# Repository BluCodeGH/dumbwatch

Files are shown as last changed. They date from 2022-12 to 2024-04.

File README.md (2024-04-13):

# DumbWatch - An offline-first E-paper smartwatch

## Images

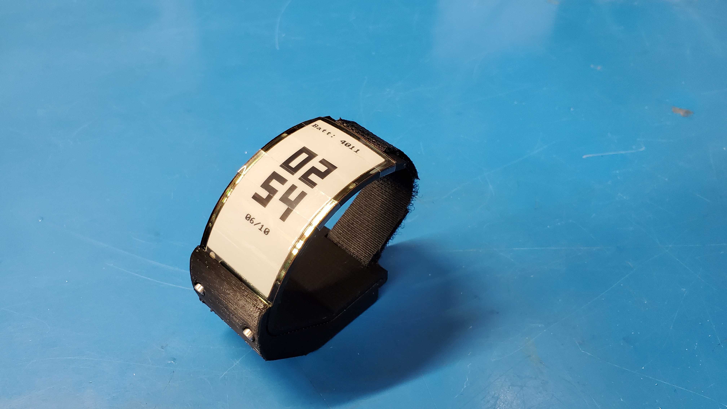
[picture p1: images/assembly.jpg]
Assembly

The final assembled watch.

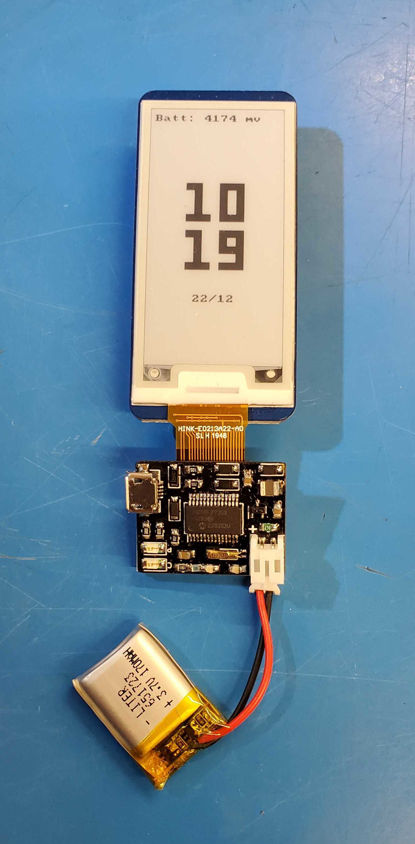
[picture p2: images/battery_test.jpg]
Battery Test

Running a battery life and RTC test using a stand-in display.

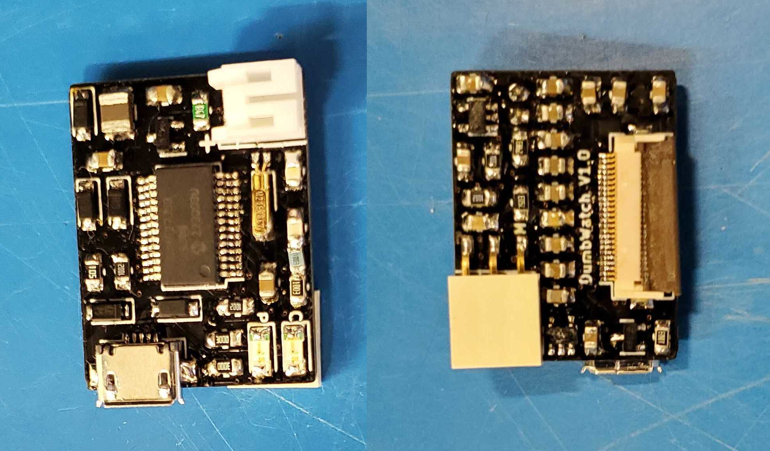
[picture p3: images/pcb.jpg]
PCB

Both sides of the custom PCB.

## Features

Dumbwatch is designed to be minimalist, with its most notable (anti-)feature being a lack of wireless connectivity. It still packs in a few nice-to-haves though:

- Two months of battery life on a 170 mAh LiPo
- LiPo charging over USB
- An E-paper dispay driver compatible with most common displays
- Communication over USB, e.g. for setting the time or loading your calendar for the day

The board is powered by the PIC18F27J53, which has an internal RTC connected to a 32.768 kHz watch crystal. I have not observed any noticble drift in the time thus far.

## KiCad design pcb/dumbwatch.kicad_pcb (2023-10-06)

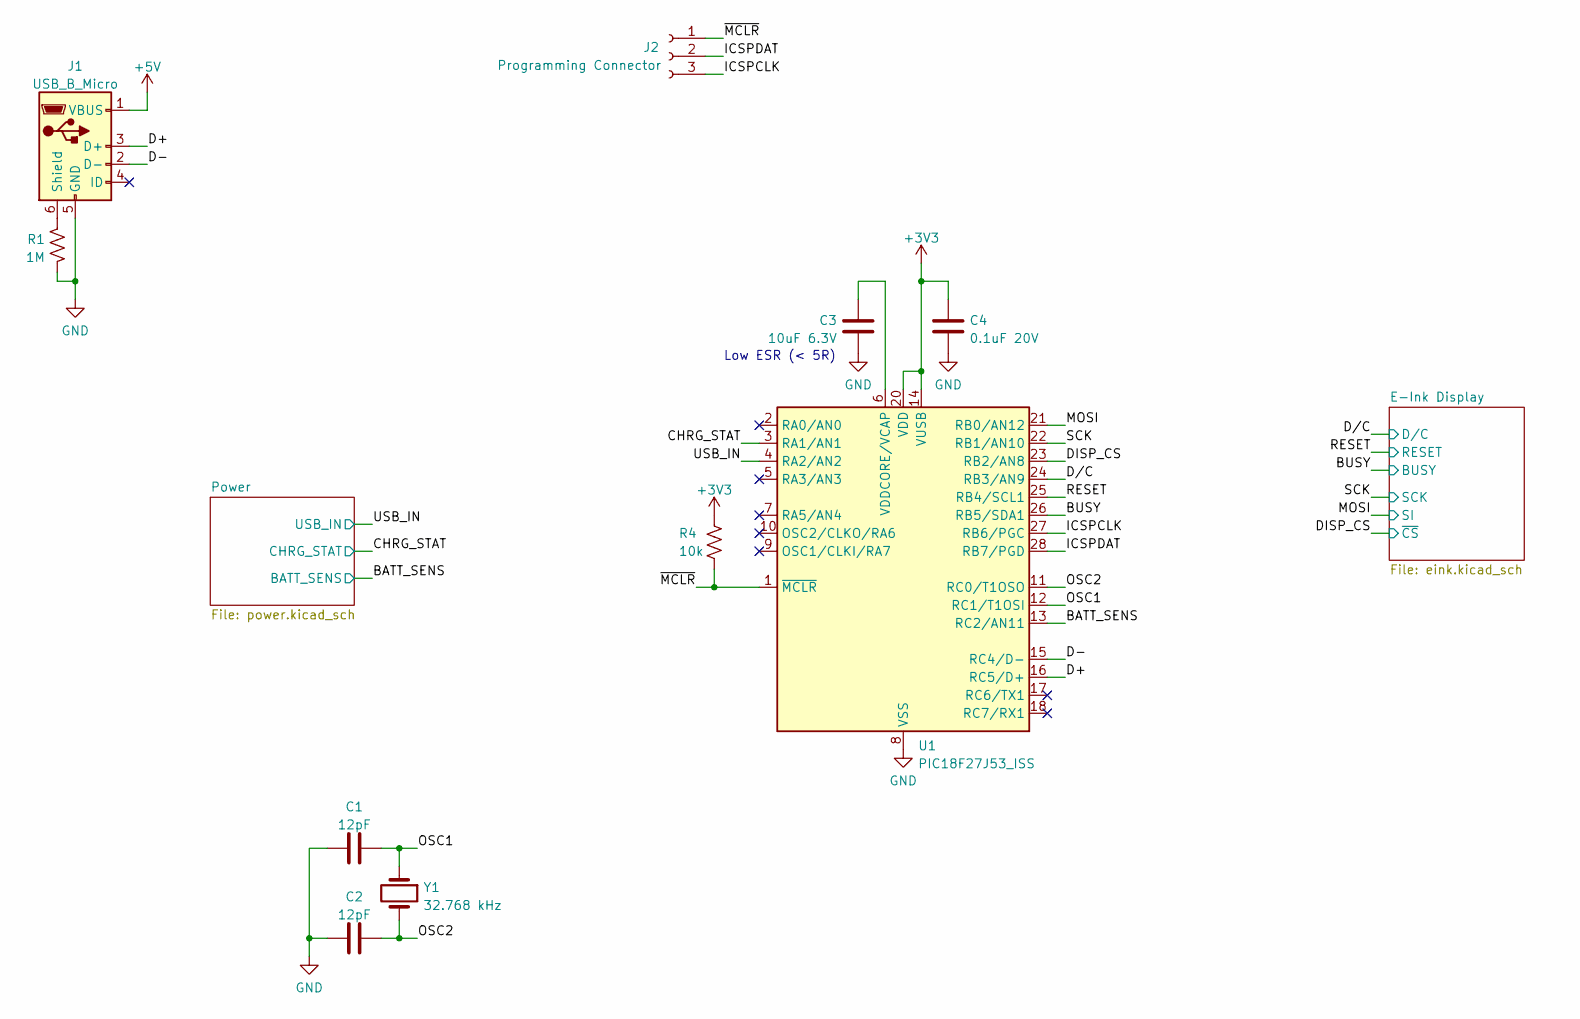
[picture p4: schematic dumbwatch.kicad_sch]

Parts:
C1, C2: 12pF; C_0805_2012Metric_Pad1.18x1.45mm_HandSolder
C3: 10uF 6.3V; C_0805_2012Metric_Pad1.18x1.45mm_HandSolder
C4: 0.1uF 20V; C_0805_2012Metric_Pad1.18x1.45mm_HandSolder
J1: USB_B_Micro; USB_Micro-B_Amphenol_10104110_Horizontal
J2: Programming Connector; PinHeader_3x2.54_SMD_90deg
R1: 1M; R_0805_2012Metric_Pad1.20x1.40mm_HandSolder
R4: 10k; R_0805_2012Metric_Pad1.20x1.40mm_HandSolder
U1: PIC18F27J53_ISS; SSOP-28_5.3x10.2mm_P0.65mm
Y1: 32.768 kHz; Crystal_SMD_MicroCrystal_MS3V-T1R

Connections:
+3V3: C4.2, R4.1, U1.14 (VUSB), U1.20 (VDD); also elsewhere on the board
+5V: J1.1 (VBUS); also elsewhere on the board
/BATT_SENS: U1.13 (RC2/AN11); also elsewhere on the board
/BUSY: U1.26 (RB5/SDA1); also elsewhere on the board
/CHRG_STAT: U1.3 (RA1/AN1); also elsewhere on the board
/D+: J1.3 (D+), U1.16 (RC5/D+)
/D-: J1.2 (D-), U1.15 (RC4/D-)
/DISP_CS: U1.23 (RB2/AN8); also elsewhere on the board
/D/C: U1.24 (RB3/AN9); also elsewhere on the board
/ICSPCLK: J2.3, U1.27 (RB6/PGC)
/ICSPDAT: J2.2, U1.28 (RB7/PGD)
/MOSI: U1.21 (RB0/AN12); also elsewhere on the board
/OSC1: C1.2, U1.12 (RC1/T1OSI), Y1.1
/OSC2: C2.2, U1.11 (RC0/T1OSO), Y1.2
/RESET: U1.25 (RB4/SCL1); also elsewhere on the board
/SCK: U1.22 (RB1/AN10); also elsewhere on the board
/USB_IN: U1.4 (RA2/AN2); also elsewhere on the board
/~MCLR: J2.1, R4.2, U1.1 (~MCLR)
GND: C1.1, C2.1, C3.1, C4.1, J1.5 (GND), R1.1, U1.8 (VSS), U1.19 (VSS); also elsewhere on the board
unnamed: C3.2, U1.6 (VDDCORE/VCAP)
unnamed: J1.6 (Shield), R1.2

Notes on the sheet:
Low ESR (< 5R)

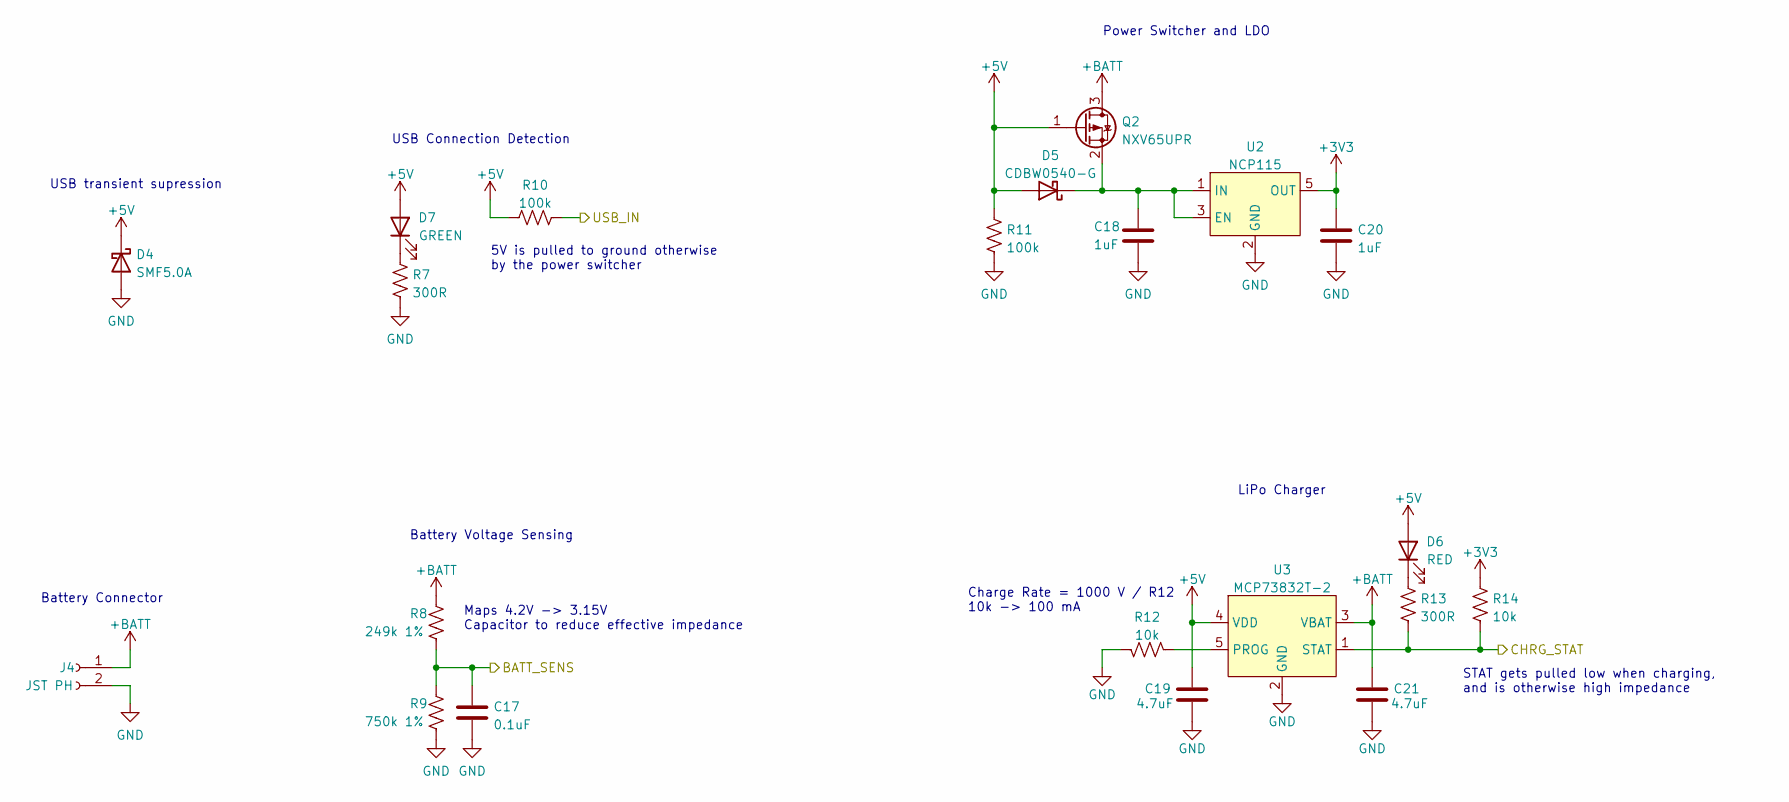
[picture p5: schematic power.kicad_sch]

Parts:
C17: 0.1uF; C_0805_2012Metric_Pad1.18x1.45mm_HandSolder
C18, C20: 1uF; C_0805_2012Metric_Pad1.18x1.45mm_HandSolder
C19, C21: 4.7uF; C_0805_2012Metric_Pad1.18x1.45mm_HandSolder
D4: SMF5.0A; D_SOD-123F
D5: CDBW0540-G; D_SOD-123
D6: RED; LED_1206_3216Metric_Pad1.42x1.75mm_HandSolder
D7: GREEN; LED_1206_3216Metric_Pad1.42x1.75mm_HandSolder
J4: JST PH; JST_PH_S2B-PH-K_1x02_P2.00mm_Horizontal
Q2: NXV65UPR; SOT-23
R7, R13: 300R; R_0805_2012Metric_Pad1.20x1.40mm_HandSolder
R8: 249k 1%; R_0805_2012Metric_Pad1.20x1.40mm_HandSolder
R9: 750k 1%; R_0805_2012Metric_Pad1.20x1.40mm_HandSolder
R10, R11: 100k; R_0805_2012Metric_Pad1.20x1.40mm_HandSolder
R12, R14: 10k; R_0805_2012Metric_Pad1.20x1.40mm_HandSolder
U2: NCP115; TSOT-23-5
U3: MCP73832T-2; SOT-23-5

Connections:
+3V3: C20.1, R14.1, U2.5 (OUT); also elsewhere on the board
+5V: C19.1, D4.1 (K), D5.2 (A), D6.2 (A), D7.2 (A), Q2.1 (G), R10.1, R11.1, U3.4 (VDD); also elsewhere on the board
+BATT: C21.1, J4.1, Q2.3 (D), R8.1, U3.3 (VBAT)
/BATT_SENS: C17.1, R8.2, R9.1; also elsewhere on the board
/CHRG_STAT: R13.2, R14.2, U3.1 (STAT); also elsewhere on the board
/USB_IN: R10.2; also elsewhere on the board
GND: C17.2, C18.2, C19.2, C20.2, C21.2, D4.2 (A), J4.2, R7.1, R9.2, R11.2, R12.2, U2.2 (GND), U3.2 (GND); also elsewhere on the board
unnamed: C18.1, D5.1 (K), Q2.2 (S), U2.1 (IN), U2.3 (EN)
unnamed: D6.1 (K), R13.1
unnamed: D7.1 (K), R7.2
unnamed: R12.1, U3.5 (PROG)

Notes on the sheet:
5V is pulled to ground otherwise by the power switcher
Battery Voltage Sensing
Charge Rate = 1000 V / R12 10k -> 100 mA
Maps 4.2V -> 3.15V Capacitor to reduce effective impedance
Battery Connector
USB Connection Detection
STAT gets pulled low when charging, and is otherwise high impedance
Power Switcher and LDO
USB transient supression
LiPo Charger

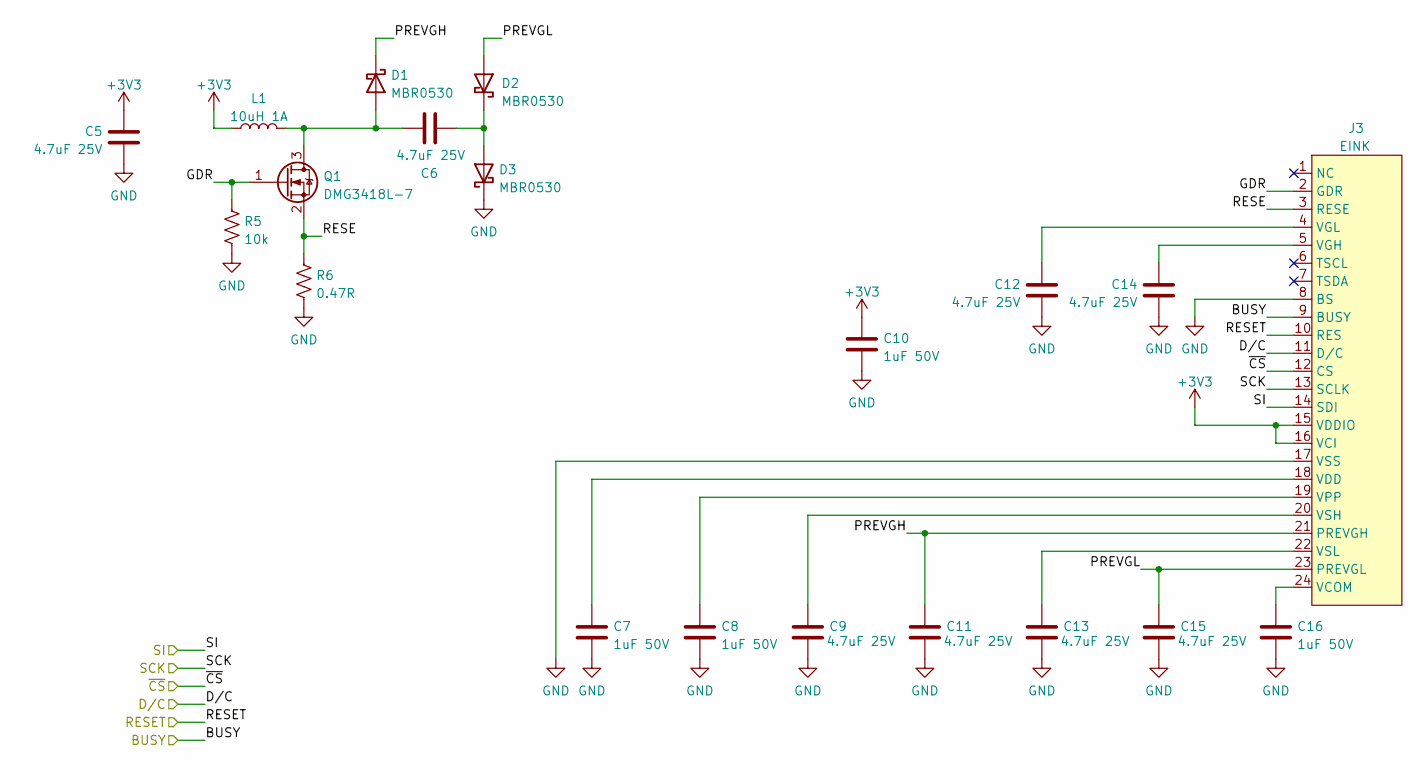
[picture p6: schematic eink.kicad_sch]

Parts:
C5, C6, C9, C11, C12, C13, C14, C15: 4.7uF 25V; C_0805_2012Metric_Pad1.18x1.45mm_HandSolder
C7, C8, C10, C16: 1uF 50V; C_0805_2012Metric_Pad1.18x1.45mm_HandSolder
D1, D2, D3: MBR0530; D_SOD-123
J3: EINK; Hirose_FH12-24S-0.5SH_1x24-1MP_P0.50mm_Horizontal
L1: 10uH 1A; L_1210_3225Metric_Pad1.42x2.65mm_HandSolder
Q1: DMG3418L-7; SOT-23
R5: 10k; R_0805_2012Metric_Pad1.20x1.40mm_HandSolder
R6: 0.47R; R_0805_2012Metric_Pad1.20x1.40mm_HandSolder

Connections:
+3V3: C5.1, C10.1, J3.15 (VDDIO), J3.16 (VCI), L1.1; also elsewhere on the board
/BUSY: J3.9 (BUSY); also elsewhere on the board
/DISP_CS: J3.12 (CS); also elsewhere on the board
/D/C: J3.11 (D/C); also elsewhere on the board
/E-Ink Display/GDR: J3.2 (GDR), Q1.1 (G), R5.1
/E-Ink Display/PREVGH: C11.1, D1.1 (K), J3.21 (PREVGH)
/E-Ink Display/PREVGL: C15.1, D2.2 (A), J3.23 (PREVGL)
/E-Ink Display/RESE: J3.3 (RESE), Q1.2 (S), R6.1
/MOSI: J3.14 (SDI); also elsewhere on the board
/RESET: J3.10 (RES); also elsewhere on the board
/SCK: J3.13 (SCLK); also elsewhere on the board
GND: C5.2, C7.2, C8.2, C9.2, C10.2, C11.2, C12.2, C13.2, C14.2, C15.2, C16.2, D3.1 (K), J3.8 (BS), J3.17 (VSS), R5.2, R6.2; also elsewhere on the board
unnamed: C6.1, D1.2 (A), L1.2, Q1.3 (D)
unnamed: C6.2, D2.1 (K), D3.2 (A)
unnamed: C7.1, J3.18 (VDD)
unnamed: C8.1, J3.19 (VPP)
unnamed: C9.1, J3.20 (VSH)
unnamed: C12.1, J3.4 (VGL)
unnamed: C13.1, J3.22 (VSL)
unnamed: C14.1, J3.5 (VGH)
unnamed: C16.1, J3.24 (VCOM)

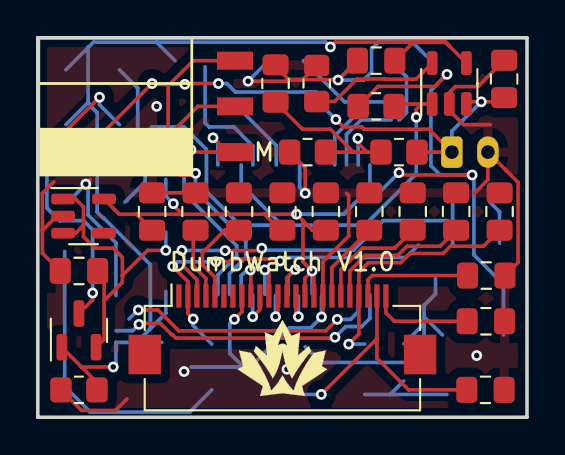
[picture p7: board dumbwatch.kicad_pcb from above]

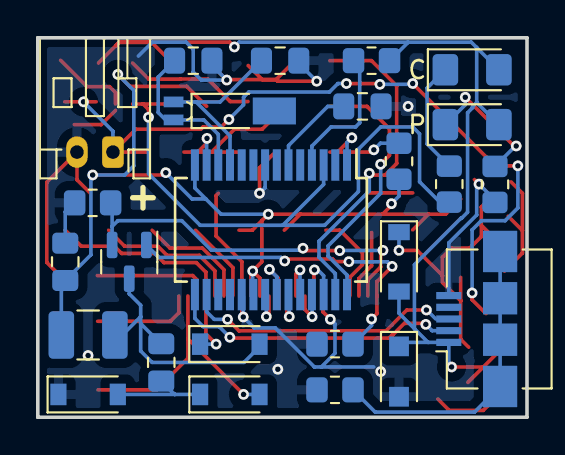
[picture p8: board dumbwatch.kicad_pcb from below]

Board: 2 copper layers, 27.2 x 21.1 mm, 51 parts (25 on the bottom side), 39 nets.

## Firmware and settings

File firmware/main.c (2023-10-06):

#include <xc.h>
#include "mcc_generated_files/usb/usb.h"
#include "mcc_generated_files/device_config.h"

#include "epd.h"
#include "usb.h"
#include "board.h"
#include "graphics.h"

void main(void) {
    // Set primary clock
    OSCTUNEbits.PLLEN = 0;
    OSCCON = 0x73;
    
    bool from_sleep = WDTCONbits.DS;
    if (from_sleep) {
        WDTCONbits.DS = 0; // Clear flag
        DSCONLbits.RELEASE = 0; // Release GPIO from values held during sleep
    }
    
    // Enable interrupts
    INTCONbits.GIE = 1;
    INTCONbits.PEIE = 1;
    
    if (!from_sleep) {
        rtc_init();
        DSGPR0 = 0; // mark that we haven't had our time set by USB
        // DSGPR0 is a general purpose register maintained in deep sleep
    }
    
    ANCON0bits.PCFG2 = 1; // Set AN2 (A2) as digital input
    TRISA2 = 1;
    if (RA2 && !DSGPR0) { // USB is connected and the time hasn't been set
        __delay_ms(500); // see if we are about to be programmed
        draw_screen_usb();
        epd_update();
        
        // Start up the fast oscillator for USB
        OSCTUNEbits.PLLEN = 1;
        OSCCON = 0x70;
        while (!OSCCONbits.OSTS);
        USBDeviceInit();
        USBDeviceAttach();

        bool success = false;
        while (!success && RA2) {
            success = usb_heartbeat();
        }
        DSGPR0 = success;
        // Clock out success message
        for (uint8_t i = 0; i < 16; i++) {
            usb_heartbeat();
        }
        USBDeviceDetach();
    } else if (!RA2) { // USB has been removed, mark ourselves as settable again
        DSGPR0 = 0;
    }
    
    draw_screen_main();
    epd_update();
    
    TRISA = 0xFF;
    TRISB = 0xFF;
    TRISC = 0xFF;
    
    // Enter deep sleep
    INTCONbits.GIE = 0;
    WDTCONbits.REGSLP = 1;
    OSCCONbits.IDLEN = 0;
    DSCONHbits.DSEN = 1;
    SLEEP();
    
    while (1);
}

void __interrupt() handler(void) {
    if (PIE2bits.USBIE == 1 && PIR2bits.USBIF == 1) {
        // USB interrupt handler
        USB_USBDeviceTasks();
    }
    if (PIR3bits.SSP2IF) {
        // SPI interrupt - ignore
    }
    if (PIR3bits.RTCCIF) {
        PIR3bits.RTCCIF = 0;
    }
    if (INTCON3bits.INT1IF) {
        // Used to wake ourselves from sleep on EPD actions complete
        INTCON3bits.INT1IF = 0;
    }
}

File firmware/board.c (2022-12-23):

#include "board.h"
#include <xc.h>

uint16_t get_batt_voltage_mv(void) {
    TRISCbits.TRISC2 = 1; // Set C2 as input
    ANCON1bits.PCFG11 = 0; // Enable analog input on C2
    ADCON1bits.ADFM = 1; // Right justify output
    ADCON1bits.ADCS = 0b110; // Select conversion clock of Fosc/64
    ADCON1bits.ACQT = 0b010; // Select aquisiton time of 4 Tad
    ADCON0bits.CHS = 11; // Select AN11
    ADCON0bits.ADON = 1; // Turn on ADC
    ADCON0bits.GO = 1; // Start conversion
    while (ADCON0bits.GO); // Wait for conversion to finish
    uint16_t batt_voltage = (((uint16_t)ADRESH) << 8) | ADRESL;
    return batt_voltage * 30 / 7; // Rough approximation of a 10 bit ADC with 3.3v power without overflowing
}

bool batt_charging(void) {
    ANCON0bits.PCFG1 = 1;
    TRISAbits.TRISA1 = 1;
    return !RA1; // active low
}

void rtc_init(void) {
    T1CONbits.TMR1CS = 0b10; // Set source to T1OSC
    T1CONbits.T1OSCEN = 1;
    T1CONbits.TMR1ON = 1;
    
     // Say the magic words to unlock the registers
    INTCONbits.GIE = 0;
    EECON2 = 0x55;
    EECON2 = 0xAA;
    RTCCFGbits.RTCWREN = 1;
    
    RTCCFGbits.RTCPTR0 = 1;
    RTCCFGbits.RTCPTR1 = 1;
    
    RTCVALL = 0;
    RTCVALH = 0; // dummy to decrement
    RTCVALL = 0;
    RTCVALH = 0;
    RTCVALL = 0;
    RTCVALH = 0;
    RTCVALL = 0;
    RTCVALH = 0;
    RTCCFGbits.RTCEN = 1;
    
    RTCCFGbits.RTCWREN = 0; // re-lock the registers
    INTCONbits.GIE = 1;
    
    // set up alarm to wake every minute
    ALRMCFGbits.CHIME = 1; // Allow alarm to repeat indefinitely
    ALRMCFGbits.AMASK = 0b0011; // Every minute
    ALRMVALL = 0x00; // On second 0
    ALRMCFGbits.ALRMEN = 1;
}

void rtc_set(uint8_t year, uint8_t month, uint8_t day, uint8_t weekday, uint8_t hour, uint8_t min) {
    while (RTCCFGbits.RTCSYNC);
    
    // Say the magic words to unlock the registers
    INTCONbits.GIE = 0;
    EECON2 = 0x55;
    EECON2 = 0xAA;
    RTCCFGbits.RTCWREN = 1;
    
    RTCCFGbits.RTCPTR0 = 1;
    RTCCFGbits.RTCPTR1 = 1;
    
    RTCVALL = year;
    RTCVALH = 0x00; // dummy to decrement
    RTCVALL = day;
    RTCVALH = month;
    RTCVALL = hour;
    RTCVALH = weekday;
    RTCVALL = 0x00; // seconds
    RTCVALH = min;
    
    RTCCFGbits.RTCWREN = 0; // re-lock the registers
    INTCONbits.GIE = 1;
    
}

void rtc_get(uint8_t *year, uint8_t *month, uint8_t *day, uint8_t *weekday, uint8_t *hour, uint8_t *min) {
    while (RTCCFGbits.RTCSYNC); // Wait until it is safe to read (ie rollover isn't possible)
    
    RTCCFGbits.RTCPTR0 = 1;
    RTCCFGbits.RTCPTR1 = 1;
    
    *year = RTCVALL;
    uint8_t foo = RTCVALH; // unused
    *day = RTCVALL;
    *month = RTCVALH;
    *hour = RTCVALL;
    *weekday = RTCVALH;
    // sec = RTCVALL;
    *min = RTCVALH;
}

void enter_sleep() {
    TRISA = 0xFF;
    TRISB = 0xFF;
    TRISC = 0xFF;
    
    PIE3bits.RTCCIE = 1;
    INTCONbits.GIE = 0;
    WDTCONbits.REGSLP = 1;
    OSCCONbits.IDLEN = 0;
    DSCONHbits.DSEN = 1;
    SLEEP();
    NOP();
}

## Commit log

2022-10-03 Routing in progress with USB C connector
    [dumbwatch.kicad_pcb, dumbwatch.kicad_sch, eink.kicad_sch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]
2022-10-23 PCB rev 1 complete
    [dumbwatch-B_Cu.gbl, dumbwatch-B_Mask.gbs, dumbwatch-B_Paste.gbp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]
2022-10-23 Remove unused libraries
    [dumbwatch.kicad_pcb, dumbwatch.kicad_sch, power.kicad_sch]
2022-11-03 First case prototype
    [case.scad, case.stl, pcb.stl]
2023-10-06 Update firmware for flexible e-paper
    [case.scad, case.stl, dumbwatch.kicad_pcb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]
2024-04-13 Add assembled image
